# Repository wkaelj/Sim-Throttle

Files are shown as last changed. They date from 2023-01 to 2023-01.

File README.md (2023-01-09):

# 3D Printed Throttle
This is my 3D printed throttle. It is mostly 3D printed, and can be used to control a flight simulator.

It uses TinyUSB and the Pico SDK to read input from a potentiometer and send it too the computer. The potentiometer is twisted by a lever connected to the handle.

## Features
1. It is customizable. The handle can be changed, and the mounting plate has a hole for wires. It is also easy to add panels on top of the case for switches or dials.
1. It is very simple. Required it made up of few peices, requires few supports to print, and is easy to assemble.
1. Inexpensive. The total cost, without filament, should be no more then \$10 CAD. A pi pico costs about \$4, and it should be easy to find a potentiometer for less then \$6.

## Materials
1. Pi Pico, or other microcontroller.
1. Potentiometer
1. 7-9 M3 Screws. 
	+ Similar sizes would work too.
	+ The handle plate really only needs two screws, the ones through the levers.
1. 3 M3 nuts (or the screw size used)

## Instructions
1. Print all the components
1. Test your potentiometer with your microcontroller. You don't have to, but I would make sure it all works before soldering it all.
1. One of the supports has a single, larger hole in it. This hole should be drilled large enough that the potentiometer can spin freely.
1. One of the levers has a larger hole. This hole should be drilled until the potentiometers spinny bit can just fit, so it cannot move.
1. Assembly the the 3D printed parts. It should be easy to see how they connects, and _Throttle.FCStd_ show it all assembled and named.
1. Connect the potentiometer. The potentiometer needs to be all the way to one way when the throttle is all the way closed. **It is critical that the potentiometer signal pin is soldered to a pin that supports ADC. On the Pi Pico this is GPIO pins 26-29**
1. Upload code to the microcontroller. You can use the .uf2 I have but it probably won't work properly, because you will have to hardcode the min/max values of the potentiometer. Also only a max value works right now. See the code section for compiling and stuff.
1. You may have to tweak the potentiometer, because I found that when my potentiometer was all the way closed I would have to push the throttle a ways before is started to change. I fixed this by going in a game and rotationg the outside of the potentiometer until it read -1/1 only when the throttle was closed.
1. Glue the potentiometer in place. You can glue it real good and hope it never drifts, but I left it kinda loose so I can fix it easier. I used hot glue.

## Code
The code is very simple. It reads the potentiometer input from a ADC pin, as a 12-bit unsigned int. It then converts it to an 8-bit signed it, and scales it using the max value defined at the top of the file.

To define the max value use the constant at the top of the file. To change the pin, set the gpio pin value in the `input_pins` struct.

### Compiling
Compiling the code is extremely difficult. First install the pico sdk (https://www.raspberrypi.com/documentation/microcontrollers/c_sdk.html). Then the compile the code using the commands.

```cmake -B build/```

```cmake --build build/```

The `.uf2` file will be in build/src/

To install the code on the pico, plug it into your computer while holding the button. It will appear as a USB drive, just copy the binary to it.

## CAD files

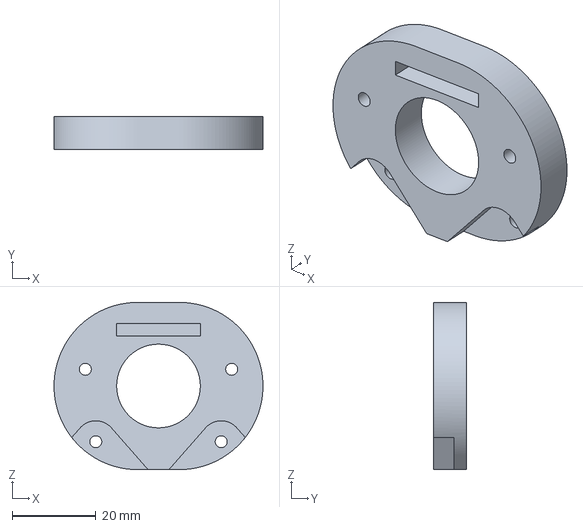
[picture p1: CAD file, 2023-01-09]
Throttle Printing/Throttle-Handle Backplate.3mf
50.0 x 8.00 x 40.0 mm

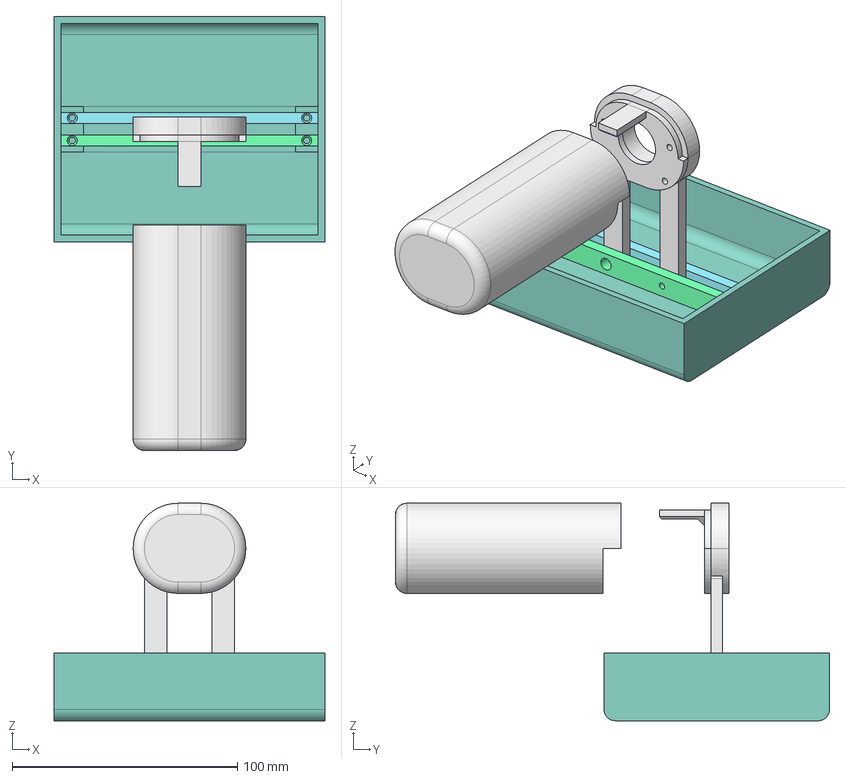
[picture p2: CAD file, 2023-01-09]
Throttle.FCStd
120.0 x 192.5 x 96.5 mm
Case
Support
Support001
Back_lever
front_lever
Handle Backplate
Handle Backplate Cover
Handle

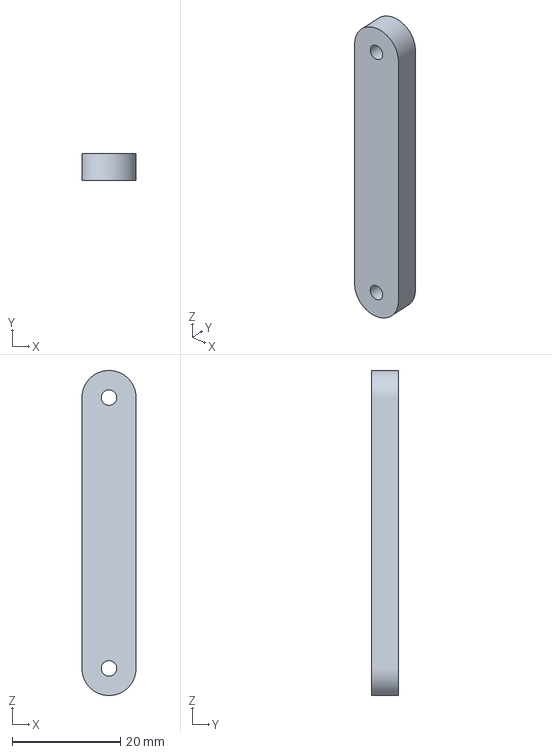
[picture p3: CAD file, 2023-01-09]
Throttle Printing/Throttle-front_lever.3mf
10.0 x 5.00 x 60.0 mm

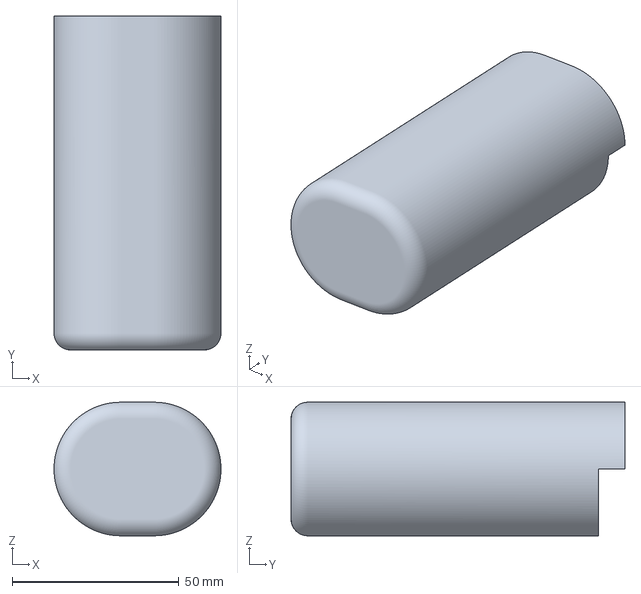
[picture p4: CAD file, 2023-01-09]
Throttle Printing/Throttle-Handle.3mf
50.0 x 100.0 x 40.0 mm

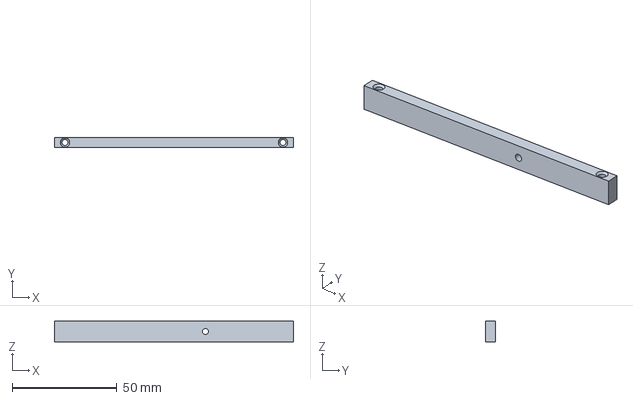
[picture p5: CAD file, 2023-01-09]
Throttle Printing/Throttle-Support001.3mf
114.0 x 5.00 x 10.0 mm

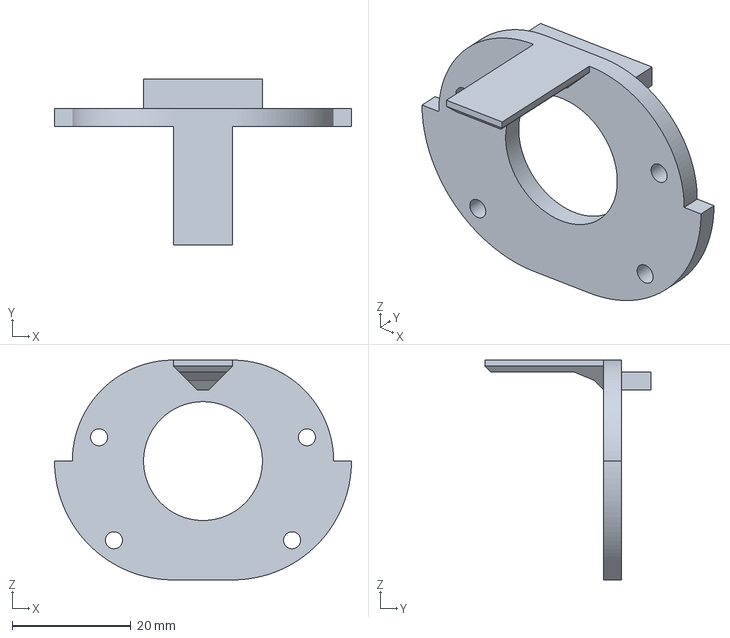
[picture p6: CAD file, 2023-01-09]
Throttle Printing/Throttle-Handle Backplate Cover.3mf
50.0 x 28.0 x 37.0 mm

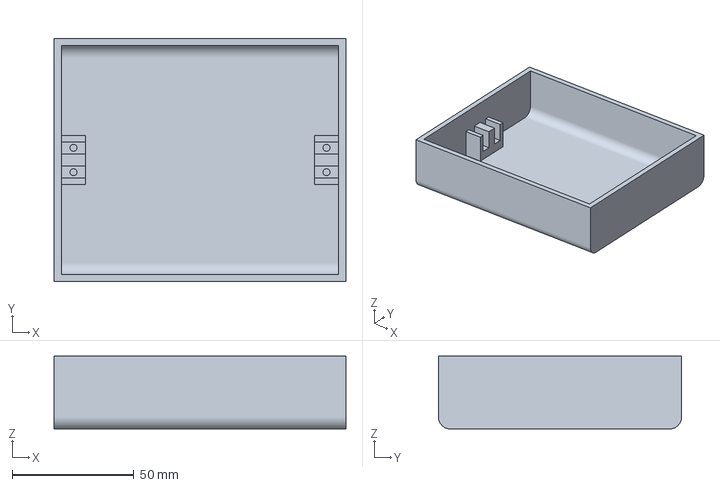
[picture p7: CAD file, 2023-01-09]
Throttle Printing/Throttle-Case.3mf
120.0 x 100.0 x 30.0 mm

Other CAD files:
Throttle Printing/Throttle-Back_lever.3mf
Throttle Printing/Throttle-Support.3mf

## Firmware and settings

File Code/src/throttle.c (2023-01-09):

#include <stdlib.h>

#include <pico/stdlib.h>
#include <hardware/gpio.h>
#include <hardware/adc.h>
#include "bsp/board.h"
#include <tusb.h>
#include "usb_descriptors.h"
#include "usb_tool.h"

#include <pico/stdio.h>

const uint16_t THROTTLE_MIN = 0, THROTTLE_MAX = 69;

struct ButtonStates
{
    // top buttons from top, going clockwise
};

struct
{
    int potentiometer;
} inputPins = {
    .potentiometer = 26,
};

void initInputPins(void);

void readThrottle(int16_t *throttle);
void readButtonStates(struct ButtonStates *out);
void calibrateThrottle(void);

// send to computer
void hidTask(void);
void sendGamepadReport(int16_t *throttle, struct ButtonStates *buttons);

void led_on(void) { gpio_put(PICO_DEFAULT_LED_PIN, 1); }
void led_off(void) { gpio_put(PICO_DEFAULT_LED_PIN, 0); }

int mmain()
{

    gpio_init(PICO_DEFAULT_LED_PIN);
    gpio_set_dir(PICO_DEFAULT_LED_PIN, GPIO_OUT);

    gpio_init(26);
    gpio_set_dir(26, GPIO_IN);

    const float conversion = 3.3f / (1 << 12);

    while (1)
    {
        if (gpio_get(26))
            led_on();
        else
            led_off();
        sleep_ms(10);
    }
}

int main()
{
    board_init();
    tusb_init();

    adc_init();

    gpio_init(PICO_DEFAULT_LED_PIN);
    gpio_set_dir(PICO_DEFAULT_LED_PIN, GPIO_OUT);

    initInputPins();

    led_on();

    // calibrateJoystick();

    while (true)
    {

        bool toggle = board_button_read();

        // turn on led if button pressed
        if (toggle)
        {
            led_off();
        }
        tud_task();
        hidTask();
    }
}

void sendGamepadReport(int16_t *throttle, struct ButtonStates *buttons)
{
    if (!tud_hid_ready())
        return;

    // generate button report
    uint16_t button_report = 0;

    // dpad

    hid_gamepad_report_t gamepad_report = {
        0,             // x stick
        0,             // y stick
        *throttle,     // z?
        0,             // x right stick
        0,             // y
        0,             // z
        0,             // hat
        button_report, // buttons
    };

    tud_hid_report(REPORT_ID_GAMEPAD, &gamepad_report, sizeof(gamepad_report));
}

bool isButtonsActive(struct ButtonStates *states) { return 0; }
void hidTask(void)
{
    // only send reports every 10 ms
    const uint32_t interval_ms = 10;
    static uint32_t start_ms   = 0;
    if (board_millis() - start_ms < interval_ms)
        return;
    start_ms += interval_ms;

    int16_t throttle = 0;
    readThrottle(&throttle);
    struct ButtonStates buttonStates;
    readButtonStates(&buttonStates);

    bool isInput = throttle != 0 || isButtonsActive(&buttonStates);
    if (isInput)
        led_off();
    else
        led_on();

    if (getUsbState() == USB_IDLE && isInput)
        tud_remote_wakeup();
    else
        sendGamepadReport(&throttle, &buttonStates);
}

int16_t convertRawThrottle(uint16_t raw)
{
    const float percentOfMax =
        (float)(THROTTLE_MAX - THROTTLE_MIN) /
        (1 << 8); // percent of potentiometer max vs actual max
    float calibratedValue = (float)raw / percentOfMax;
    int16_t finalValue    = (int16_t)calibratedValue - INT16_MAX - THROTTLE_MIN;

    return ~(int16_t)((raw >> 4) / percentOfMax - 128); // convert to 8-bit
}

// read joystick input
void readThrottle(int16_t *out)
{
    adc_select_input(abs(26 - inputPins.potentiometer));
    uint16_t raw = adc_read();
    *out         = convertRawThrottle(raw);
}

// read button input
void readButtonStates(struct ButtonStates *out)
{
    *out = (struct ButtonStates){};
}

void initBtnPin(unsigned pin)
{
    gpio_init(pin);
    gpio_set_dir(pin, GPIO_IN);
    gpio_pull_down(pin);
}

void initInputPins(void) { adc_gpio_init(inputPins.potentiometer); }

// tusb callbacks

void tud_hid_report_complete_cb(
    uint8_t instance, uint8_t const *report, uint8_t len)
{
    (void)instance;
    (void)len;

    uint8_t next_report_id = report[0] + 1;

    if (next_report_id == REPORT_ID_GAMEPAD)
    {
        int16_t throttle;
        readThrottle(&throttle);
        struct ButtonStates buttonStates;
        readButtonStates(&buttonStates);
        sendGamepadReport(&throttle, &buttonStates);
    }
}

uint16_t tud_hid_get_report_cb(
    uint8_t instance,
    uint8_t report_id,
    hid_report_type_t report_type,
    uint8_t *buffer,
    uint16_t reqlen)
{
    // TODO not Implemented
    (void)instance;
    (void)report_id;
    (void)report_type;
    (void)buffer;
    (void)reqlen;

    return 0;
}

void tud_hid_set_report_cb(
    uint8_t instance,
    uint8_t report_id,
    hid_report_type_t report_type,
    uint8_t const *buffer,
    uint16_t bufsize)
{
    (void)instance;

    // ignore input
}

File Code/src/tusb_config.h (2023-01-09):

#ifndef TUSB_CONFIG_H
#define TUSB_CONFIG_H

//--------------------------------------------------------------------
// DEVICE CONFIGURATION
//--------------------------------------------------------------------
// #define BOARD_DEVICE_RHPORT_NUM     0
#define BOARD_DEVICE_RHPORT_SPEED OPT_MODE_HIGH_SPEED
#define CFG_TUSB_RHPORT0_MODE (OPT_MODE_DEVICE | BOARD_DEVICE_RHPORT_SPEED)
#define CFG_TUD_ENDPOINT0_SIZE 64

//------------- CLASS -------------//
#define CFG_TUD_CDC 0
#define CFG_TUD_MSC 0
#define CFG_TUD_HID 1
#define CFG_TUD_MIDI 0
#define CFG_TUD_VENDOR 0

// MIDI FIFO size of TX and RX
#define CFG_TUD_MIDI_RX_BUFSIZE (TUD_OPT_HIGH_SPEED ? 512 : 64)
#define CFG_TUD_MIDI_TX_BUFSIZE (TUD_OPT_HIGH_SPEED ? 512 : 64)

#endif
